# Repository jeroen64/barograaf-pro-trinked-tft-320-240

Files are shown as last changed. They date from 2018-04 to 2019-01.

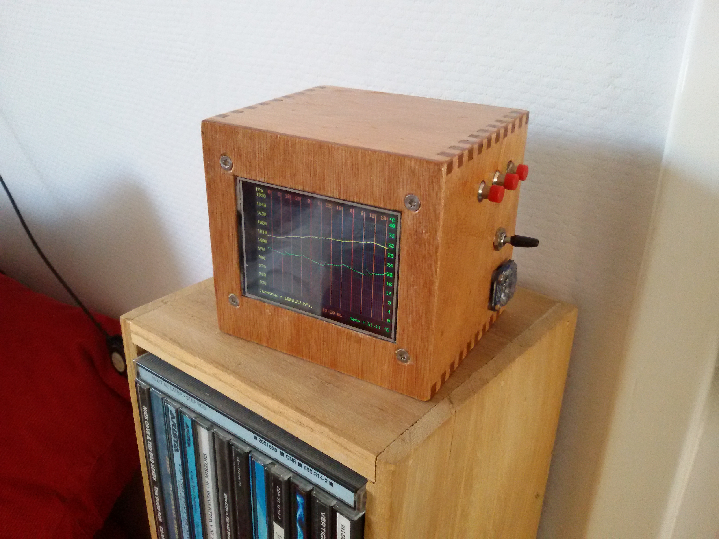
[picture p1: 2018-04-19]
overview.jpg

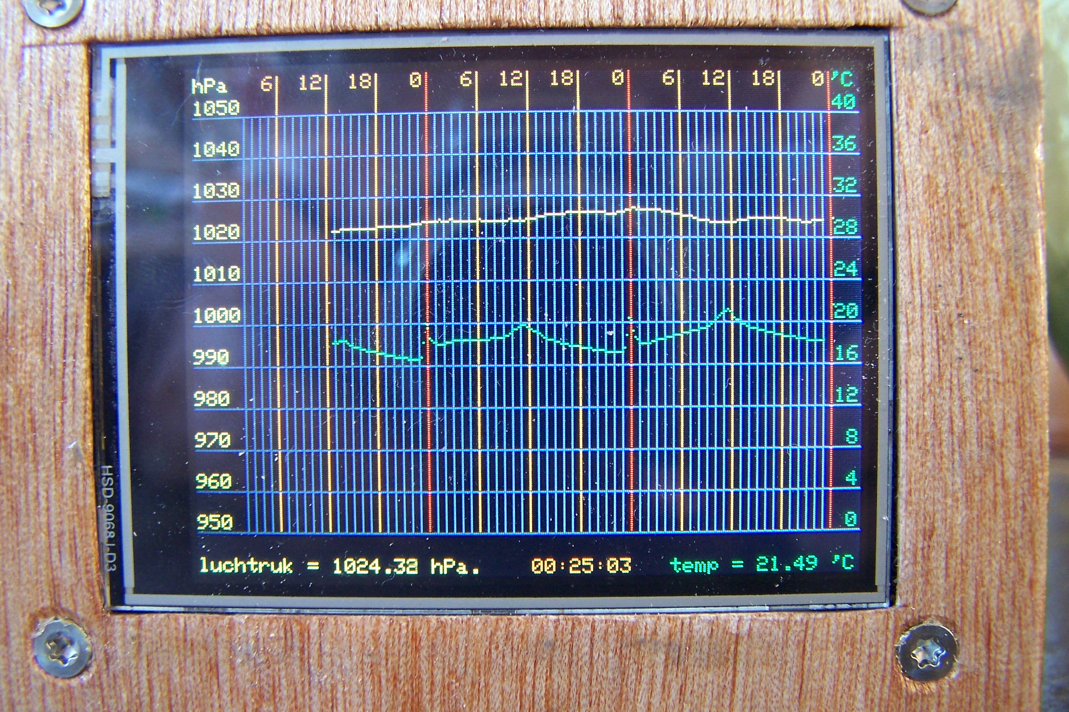
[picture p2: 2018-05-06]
front.JPG

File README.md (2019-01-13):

Graphic weather station
This thing measures the temperature and airpressure and logs this to a graph every 15 minutes. It has 283 pixels to do so, wich is almost enough for 3 days. You can set the time, and calibrate the temp and airpr. by a menu. All parts are build in an old cicar box, exept for the BMP280, whitch is mounted outside. The BMP280 noticed a warmth coming from the screen. For protection most parts of the BMP280 are covered with hot glue.

Its powered by micro USB. A powerloss means a loss of all datapoints, but you can save the graph in EEprom  before you unplug. A timestamp is also saved and used to check, if the saved data is still valid. Old data is ignored and inactivity is given as blanks.

The thinking is done by a PRO TRINKET 3,3 V . The measeruments by a BMP 280 breakout. The timekeeping by A DS 3231. A 2.8" TFT LCD shows whats going on. All Adafruit products.

On the screen. The yellow line gives the airpressure. The green line gives the teperature. The vertical lines are hours. The red verticals are days. The orange verticals are 6 hour intervals.
For powersaving the screenleds can be powered off.

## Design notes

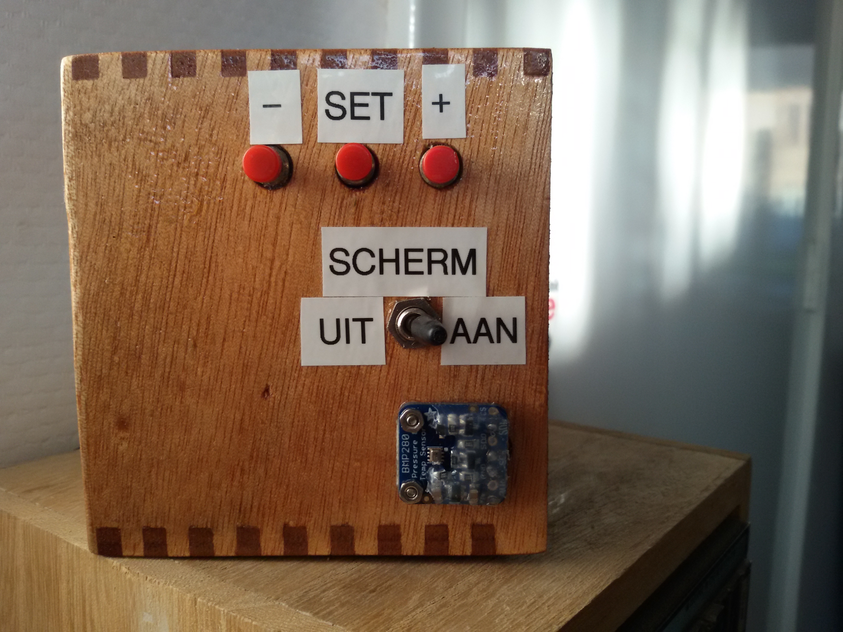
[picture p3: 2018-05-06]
left side.jpg

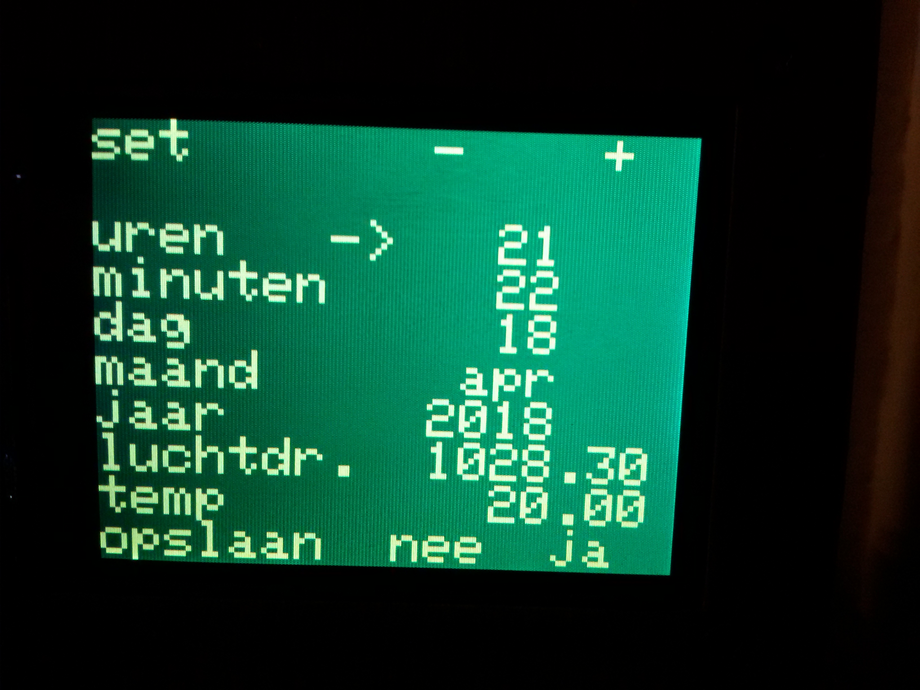
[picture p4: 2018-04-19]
setting screen.jpg

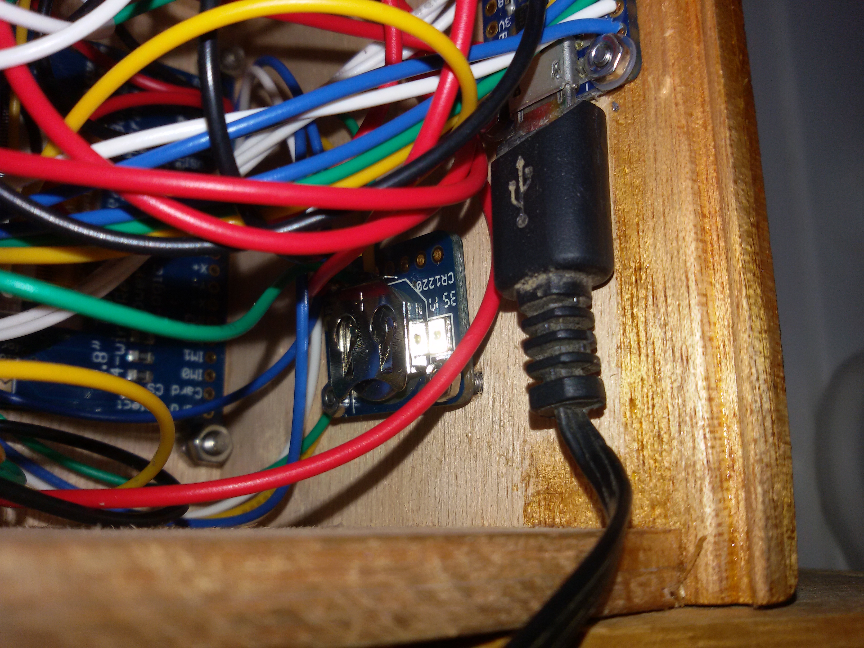
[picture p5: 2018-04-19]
DS3231.jpg

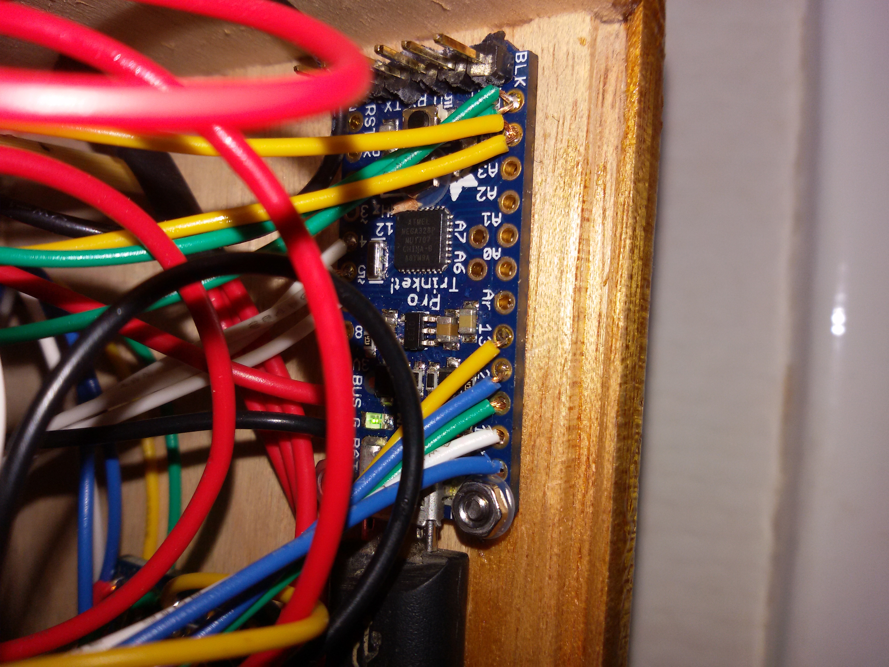
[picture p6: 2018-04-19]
protrinket.jpg

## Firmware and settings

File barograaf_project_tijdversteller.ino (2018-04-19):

 
#include <Wire.h>               //RTC  en BMP
#include "SPI.h"                //TFT  en BMP
#include <Adafruit_ILI9341.h>   //TFT
#include <Adafruit_GFX.h>       //TFT
#include <Adafruit_Sensor.h>    //BMP
#include <Adafruit_BMP280.h>    //BMP 
#include <RTClib.h>             //RTC 
#include <EEPROM.h>             //Resident geheugen 
RTC_DS1307 rtc;                 //RTC
#define TFT_DC 9                //TFT
#define TFT_CS 10               //TFT

Adafruit_ILI9341 tft = Adafruit_ILI9341(TFT_CS, TFT_DC);   //TFT
Adafruit_BMP280 bme;     // I2C voor de BMP
 byte druk[319] ;        // De array die de lijngrafiek maakt voor barometer
 byte temp[319] ;        //  De array die de lijngrafiek maakt voor thermometer    
const byte upbut   =6;           
const byte selbut  =5;              // de drie drukknoppen voor tijdverstelling. 
const byte downbut =4;               // vooor pin  digital 4 5 6
unsigned long recent,past;
int uur;
int minuut;
byte dag;
byte maand;
char maanden[12] [4] = {"jan", "feb", "mrt", "apr", "mei", "jun", "jul", "aug", "sep", "okt", "nov", "dec"};
int jaar;
int barocorr;            // correctie voor de barometerstand
byte barobyte;
int tempcorr;            // correctie voor de temperatuur  
byte tempbyte;

void setup() {         //=================SETUP=================================================
  rtc.begin();
  bme.begin();               
  tft.begin();
  DateTime now = rtc.now();
  Serial.begin(9600); 
 pinMode( selbut, INPUT_PULLUP); 
 pinMode(  upbut, INPUT_PULLUP);
 pinMode(downbut, INPUT_PULLUP);
  tft.setRotation(3);          //zet het scherm horizontaal landscape 0,0 is linksboven 319,0 rechtsboven
 barobyte =  EEPROM[0] ;            // Correctie luchtdruk
 tempbyte =  EEPROM[1] ;            // Correctie temp
             Serial.println(" barobyte en tempbyte   ");
if (barobyte != 0)
 {barocorr= int(barobyte-127);}
if (tempbyte != 0)
 {tempcorr= int(tempbyte-127);}
             Serial.print("barobyte  = ");
             Serial.println(barobyte);             
             Serial.print("barocorr = ");
             Serial.println(barocorr);
             Serial.print("tempbyte = ");
             Serial.println(tempbyte);                          
              Serial.print("tempcorr = ");
             Serial.println(tempcorr);    
 past = EEPROMReadlong( 600 );  // past is nu de waarde die staat op 600
             Serial.print("past =  ");      // this is unix time since data saving
             Serial.println(past);            
 recent = now.unixtime();
            Serial.print(" recent = ");
            Serial.println(recent);
 recent=recent-past;   // recent is nu tijdverschil sinds laatste power down.in secondes
            Serial.print(" tijdverschil =   ");
            Serial.println (recent  );
 recent=recent/900;     // het aantal kwartieren power down = recent /60 /15 = recent/900
              Serial.println("  tijdverschil in kwartieren =  ") ;
              Serial.println(recent); 
         for (int a=24; a<=306; a++)      // hier worden oude meetwaardes opgehaald uit het EEprom
               {druk[a] = EEPROM[a- 22];   // druk[ 24]staat dus op EEpromplaats 2  24- 22=  2
                                           // druk[306]staat dus op EEPromplaats   306- 22=284
                temp[a] = EEPROM[a+261]; } //   temp[24]staat op  285    ,,      24+261=285 
                                            //  temp[306]staat op  567    ,,     306+261=567
 if (recent >= 283) { recent = 283; } // if power down is longer then 283 kwartieren , make alle 283 kwartieren 0                             
   for (int x = 0 ; x <= recent ; x++)      // Het aantal kwartieren dat de grafiek moet worden opgeschoven en met nullen gvuld                          
         { druk[306]=0;
           temp[306]=0;
    //   Serial.print(" druk 306  =  ");
     //  Serial.println( druk [306]);
         for (int a=24; a<=306; a++)      
                    { druk[a]=druk[a+1]; 
                      temp[a]=temp[a+1];}  }
   
 tft.fillScreen(ILI9341_BLACK);     //maak scherm zwart
  tft.setTextSize (1);
    verlijnen();
    horlijnen();
druklijnmaker();
templijnmaker();
}
void loop(void) {  //=====================LOOP=================================================================   
DateTime now = rtc.now();
//Serial.println(" Loop started  ");
 tft.setTextSize (1);
 if (now.minute()%15==0  &&  now.second()==0) //activeert de grafiek elke 15 minuten 
                { tft.fillScreen(ILI9341_BLACK);   
                  verlijnen();
                  horlijnen();     
                  druklijnmaker();
                  templijnmaker(); }  
 minitijdprinter();
 if  (digitalRead(selbut)==LOW) 
      { tijdprinter();
           delay(200);
         timesetter();  } 
 }   //==================================Loop einde====================================
void minitijdprinter()  // =========================minitijdprinter===============
{ DateTime now = rtc.now();   // print de tijd , luchtruk , en temp op onderste regel op elke seconde
  tft.setCursor(0,232);
  tft.setTextColor(ILI9341_YELLOW,0);
         //   float a = float(decapascals()/ 10.0); 
         float a = (bme.readPressure()/100.0) + (barocorr/10.0);    
         tft.print("luchtruk = ");
         if (a<1000){tft.print(" ");}
         tft.print (a);tft.print(" hPa.    ");
         tft.setTextColor(ILI9341_ORANGE,0);
                if (now.hour()<10){ tft.print("0");}
          tft.print(now.hour(),DEC);
          tft.print(':');
               if (now.minute()<10){ tft.print("0");}
         tft.print(now.minute(), DEC);
          tft.print(':');
               if (now.second()<10){ tft.print("0");}
         tft.print(now.second(), DEC);                   
          float b =(bme.readTemperature())+( tempcorr/10.0);
         tft.setTextColor(ILI9341_GREEN,0);
            tft.print("   temp = ");tft.print (b);tft.print(" 'C");
}
//--------------------------------------minitijdprinter einde------------------------
void verlijnen() //----------tekent de verticale lijnen en tijd aanduiding-----------------------------------------
{
  DateTime now = rtc.now();
byte minut  = now.minute();
byte punt=(minut/15);             
byte uur = now.hour();
unsigned int kleur;
for (int x=306; x>25; x-=4)            // gewijzigd for (int x=306; x>24; x-=4)  
   { byte bklijn;
     byte letterplek;  
   if      (uur==0){kleur= ILI9341_RED;bklijn=0;}
  else             { if (uur%6 == 0 && uur != 0)
                           { bklijn = 0; kleur = ILI9341_ORANGE;} 
                      else { bklijn =19; kleur = ILI9341_DARKGREY;} }//gewijzigd orange en anders grijs  
   tft.drawLine(x-punt, bklijn, x-punt, 219,kleur);
   if (uur<10) {letterplek=8;} else {letterplek=14;}
   tft.setCursor(x-letterplek,0);
   tft.setTextColor(ILI9341_ORANGE,0);   
   if (uur%6==0){tft.print(uur);}  //gewijzigd
   uur--; if ( uur> 24) {uur=23;}  // uur is byte. . . negatief wordt 255  . . is groter dan 24
   }   
  }//----------------------einde verlijnen----------------------------------------------------------------------
void druklijnmaker() //--------------------druklijnmaker------------- druk-------------------------------------
{                       // maakt de eigenlijke grafiek van links naar rechts 
                        //luchtdruk grafiekmaker
                 int b = float(decapascals()/-5.0)+2119; //  5 decapascals per pixel
                                                        // druk worden de daadwerkelijke beeldpunten. 1/2 millibar per pixel  
            (float(bme.readPressure())+(float( barocorr)))/50 +2119 ;
     if (b< 19) {b+=200;}          // beeldpunten buiten het bereik worden naar boven of onder doorgegeven.
     if (b>220) {b-=200;}          // bovenaan 306-24=282 beeldpunten reserveren
  druk[306]=b;
       for (int a=24; a<=306; a++)                                
         {  if (druk[a] !=0)
             { Serial.println(druk[306]);
               tft.drawPixel(a,druk[a],ILI9341_YELLOW);}           //schrijft 1 beeldpunt
               druk[a]=druk[a+1];              }                   // schuift alle punten 1 door
      
 }  //-------------einde druklijnmaker-------------------------------------------------------------------------------
 void templijnmaker() //--------------------templijnmaker------------- temp-------------------------------------
{                       // maakt de eigenlijke grafiek van links naar rechts 
                        //  temp grafiekmaker
 int b = float (tiendengraden()*-0.5)+219 ;  // temp worden de daadwerkelijke beeldpunten. 0.2 'C per pixel  negatief want o.o is rechtsboven
     if (b< 19) {b+=200;}          // beeldpunten buiten het bereik worden naar boven of onder doorgegeven.
     if (b>220) {b-=200;}
  temp[306]=b;
       for (int a=24; a<=306; a++)                                 // links 24 pixels vrij en rechts 320-14=306 voor de legenda
         {  if (temp[a] !=0)                                       // Lege beeldpuntenn worden niet geprint
             {   Serial.println("temp in templijnmaker   ");Serial.println(temp[306]);
               tft.drawPixel(a,temp[a],ILI9341_GREEN);}           //schrijft 1 beeldpunt
               temp[a]=temp[a+1];              }                  //schuift alle beeldpunten 1 op      
 }  //-------------einde templijnmaker-------------------------------------------------------------------------------

void horlijnen()//--------------------- geeft horizontale lijnen en luchtdrukwaardes 1050 tot 950 als achtergrond
  {
   tft.setCursor(0,0);tft.setTextColor(ILI9341_YELLOW);
   tft.fillRect(0, 0, 24, 8, ILI9341_BLACK);
   tft.print("hPa");
   tft.setCursor(306,0);tft.setTextColor(ILI9341_GREEN);
   tft.fillRect(306, 0, 12, 8, ILI9341_BLACK);
   tft.setCursor(306,0); 
   tft.print("'C");
  int druk=1050;    // eerste luchtdruk lijn
  byte temp= 40 ;            
    for (byte x=19; x<239; x+=20)
          { tft.setCursor(0,x-8);
            tft.setTextColor(ILI9341_YELLOW);
            tft.print(druk);
            druk-=10;
            tft.drawFastHLine (0,x,320,ILI9341_DARKGREY);
            tft.setCursor(307,x-8);
            tft.setTextColor(ILI9341_GREEN);
            if (temp<10){tft.print(" ");}
            tft.print(temp);
            temp-=4;       }
  }  //----------------------------------------------------------------------------------------------------
   void timesetter() {   //-----------------------------timesetter----------------------------
    DateTime now = rtc.now();               
 jaar   = now.year();
 maand  = now.month();
 dag    = now.day();
 uur    = now.hour();
 minuut = now.minute();
 tft.setTextSize (3);
   tft.setCursor(7*18,2*24);// ---urensteller-----     
   tft.print("->");  
 while(digitalRead(selbut )==HIGH)  {
      if (digitalRead(  upbut)==LOW){uur++; if (uur > 23){uur = 0;}}   // houd de uren tussen 0 en 24
      if (digitalRead(downbut)==LOW){uur--; if (uur < 0){uur = 23;}} 
      rtc.adjust(DateTime(jaar,maand,dag,uur,minuut,0)); // This line sets the RTC with an explicit date & time      
      tft.setCursor(12*18,2*24);                       // 12 plaatsen naar rechts en 3 plaatsen naar beneden
      if (uur  < 10)   { tft.print  ("0");}   // replacing space by the low numbers
       tft.print(uur);     
      delay(200);} 
      tft.setCursor(7*18,2*24);
      tft.print("  "); 
      delay(200);   
 tft.setCursor(7*18,3*24); //--- minutensteller----
 tft.print("->");        
 while(digitalRead(selbut )==HIGH)  {
      if (digitalRead(  upbut)==LOW){minuut++; if (minuut > 59){minuut = 0;}} // houd de minuten tussen 0 en 59
      if (digitalRead(downbut)==LOW){minuut--; if (minuut < 0){minuut = 59;}} 
      rtc.adjust(DateTime(jaar,maand,dag,uur,minuut,0)); // This line sets the RTC with an explicit date & time      
      tft.setCursor(12*18,3*24);                       // 12 plaatsen naar rechts en 3 plaatsen naar beneden
      if (minuut  < 10)   { tft.print  ("0");}        // replacing space by the low numbers
       tft.print(minuut);     
      delay(200);} 
 tft.setCursor(7*18,3*24); 
 tft.print("  ");  
 delay(200);      
 tft.setCursor(7*18,4*24); //---dagsteller-------
 tft.print("->");        
 while(digitalRead(selbut )==HIGH)  {
      if (digitalRead(  upbut)==LOW){dag++; if (dag > 31){dag = 1;}}    // houd  de dagen tussen 0 en 31
      if (digitalRead(downbut)==LOW){dag--; if (dag < 1){dag = 31;}} 
      rtc.adjust(DateTime(jaar,maand,dag,uur,minuut,0)); // This line sets the RTC with an explicit date & time      
      tft.setCursor(12*18,4*24);                       // 12 plaatsen naar rechts en 3 plaatsen naar beneden
      if (dag  < 10)   { tft.print  ("0");}   // replacing space by the low numbers
       tft.print(dag); 
       delay(200);} 
  tft.setCursor(7*18,4*24);
  tft.print("  ");              
  delay(200);      
 tft.setCursor(7*18,5*24); //--- maandsteller------
 tft.print("->");        
 while(digitalRead(selbut )==HIGH)  {
      if (digitalRead(  upbut)==LOW){maand++; if (maand > 12){maand = 1;}}   //  houd de maanden tussen jan en dec 
      if (digitalRead(downbut)==LOW){maand--; if (maand < 1){maand = 12;}} 
      rtc.adjust(DateTime(jaar,maand,dag,uur,minuut,0)); // This line sets the RTC with an explicit date & time      
      tft.setCursor(11*18,5*24);                       // 12 plaatsen naar rechts en 3 plaatsen naar beneden  
      tft.print( maanden[maand - 1]);     
       delay(200);} 
  tft.setCursor(7*18,5*24);
  tft.print("  ");              
  delay(200); 
 tft.setCursor(7*18,6*24); //---jaarsteller------
 tft.print("->");        
 while(digitalRead(selbut )==HIGH)  {
      if (digitalRead(  upbut)==LOW){jaar++; if (jaar > 2100){jaar = 2017;}} // jaar tussen 2017 en 2100 
      if (digitalRead(downbut)==LOW){jaar--; if (jaar <2017){jaar = 2100;}} 
      rtc.adjust(DateTime(jaar,maand,dag,uur,minuut,0)); // This line sets the RTC with an explicit date & time      
      tft.setCursor(10*18,6*24);                        // 12 plaatsen naar rechts en 3 plaatsen naar beneden  
      tft.print(jaar);     
       delay(200);} 
  tft.setCursor(7*18,6*24);
  tft.print("  ");              
  delay(200);   
 tft.setCursor(7*18,7*24); //---luchtdruk correctie per 10 Pascal= 0.1 hPa  tot max + of - 12,7  hPa ---------
 tft.print("->");        
 while(digitalRead(selbut )==HIGH)  {
      if (digitalRead(  upbut)==LOW){barocorr+=1; if (barocorr >  127){barocorr = -127;}}   
      if (digitalRead(downbut)==LOW){barocorr-=1; if (barocorr < -127){barocorr =  127;}} 
      Serial.print(" barocorr =  ");
    Serial.println( barocorr   );
      tft.setCursor(10*18,7*24);                       // 12 plaatsen naar rechts en 3 plaatsen naar beneden      
     float a = float(decapascals()/10.0);
     Serial.print(" bme luchtdruk = ");
     Serial.println( bme.readPressure()   );
     Serial.print(" gecorrigeerde luchtdruk =  ");
     Serial.println (a );
     if (a<1000){tft.print(" ");} 
        barobyte= (barocorr)+127;   
     tft.print(a) ;                //a is de luchtdruk in mbar op 1 decimaal precies
       delay(200);} 
  tft.setCursor(7*18,7*24);
  tft.print("  ");              
  delay(200);            
 tft.setCursor(7*18,8*24); //-------------temp correctie per 0,1  'Celcius------------------------------
 tft.print("->");        
 while(digitalRead(selbut )==HIGH)  {
          if (digitalRead(  upbut)==LOW){tempcorr++; if (tempcorr >  127){tempcorr = -127;}}   
          if (digitalRead(downbut)==LOW){tempcorr--; if (tempcorr < -127){tempcorr =  127;}}
          tempbyte = tempcorr+127;     
          float  b = float (tiendengraden()/10.0); 
          Serial.print(" tempcorr =  ");
          Serial.println(tempcorr);    
          tft.setCursor(12*18,8*24); 
          if (b<10){tft.print(" ");} 
          tft.print (b); // b is de temperatuur op 1 decimaal precies.
          delay(200);} 
  tft.setCursor(7*18,8*24);
  tft.print("  ");              
  delay(200);          
                          // ------ correctiewaardes omzetten naar bytes en opslaan------------------
     tft.setCursor(8*18,13*24);  
   while(digitalRead(selbut )==HIGH){
    tft.setCursor(12*18,9*24);
                tft.print("--");
                delay(100);
                tft.setCursor(12*18,9*24);
                tft.print("  "); 
                delay(100);          
         
         if (digitalRead(downbut)==LOW){             
              tft.setCursor(12*18,9*24);
              tft.print("  ");           // somehow the space here is needed to prevent error on next screen
              return;                   }//------- return so no data is saved --------
         if (digitalRead(  upbut)==LOW){             //------ here correctionfactor temp and press data and time is being saved
                                 tft.setCursor(8*18,13*24);
                                 tft.print("saving ");                                
                                EEPROM[0]= barobyte;            //EEProm  Correctie luchtdruk
                                EEPROM[1]= tempbyte;            //EEProm  Correctie temp
                                                        
                                for (int a=24; a<=306; a++)       // opslag van druk en temp lijn
                                    {EEPROM[a-22] = druk[a];      // druk[24]komt dus op EEpromplaats 2  24- 22=  2
                                                                  // druk[306]komt dus op EEPromplaats  306- 22=284
                                     EEPROM[a+261]= temp[a];}     // temp[24] moet komen op 285          24+261=285 
                                                                  // temp[306] komt dus op  567         306+261=567
                                 recent= now.unixtime();                              
                                EEPROMWritelong( 600,recent ); // unix time is being saved at eeprom place 600
                                Serial.println( recent );                   
                                 tft.setCursor(8*18,13*24);
                                 tft.print("done ");
                                 delay(300);
                                 return ;                   }
               
    }
   }
  //-------------------------------------------------------------- einde timesetter---------------------
  void tijdprinter() {      //-----------------------------------tijdprinter grote letters---------------
  DateTime now = rtc.now();
  tft.fillScreen( ILI9341_DARKGREEN);
  tft.setCursor(0,0);
  tft.setTextColor (ILI9341_YELLOW, ILI9341_DARKGREEN);
  tft.setTextSize (3);
                                 tft.println("set       -    + ");  
                                 tft.println();       
                                 tft.print  ("uren        ") ;
       if (now.hour()  < 10)   { tft.print  ("0");}            // replacing space by the low numbers
                                 tft.println(now.hour(), DEC);
                                 tft.print  ("minuten     ") ;                            
        if (now.minute()< 10)  { tft.print  ("0");}
                                 tft.println(now.minute(), DEC);
                                 tft.print  ("dag         ");
         if  (now.day()< 10)   { tft.print  ("0");}
                                 tft.println(now.day(), DEC);
                                 tft.print  ("maand      ");
                                 tft.println( maanden[now.month() - 1]);
                                 tft.print  ("jaar      ");
                                 tft.println(now.year(), DEC);
                                 tft.print  ("luchtdr.  ");                                 
       float a= float(decapascals()/10.0);
           if (a<1000)          {tft.print  (" ");}
                                 tft.println(a) ;          
                                 tft.print  ("temp        ");
       float b =   float ( tiendengraden()/10);
                                 tft.println(b) ;  
                                tft.print ("opslaan  nee  ja");
                                                 
 }    // einde tijdprinter============================================================================================
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
